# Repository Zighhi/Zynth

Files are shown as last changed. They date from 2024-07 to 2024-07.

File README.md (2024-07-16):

# Zynth

This was my Bachelor's degree project, where I designed a monophonic and semi-modular Digitally Controlled Analog Sound Synthesizer named **The Zynth**.

## Key Components

The synthesizer includes the following key components:

- **Voltage-Controlled Oscillators (VCOs):** Generates sine, triangle, sawtooth, and square waveforms.
- **Voltage-Controlled Filter (VCF):** Low-pass filter with adjustable cutoff frequency and resonance.
- **Voltage-Controlled Amplifier (VCA):** Modulates the amplitude of the synthesized signal.
- **Mixer:** Combines signals from the oscillator.
- **Amplitude Modulators:** Configurable ADSR envelope generator and LFO for modulation.
- **MIDI Interface:** Allows real-time musical note control.
- **Display:** Visualizes set parameters.

## Digital Control

The digital control is implemented using a Raspberry Pi Pico microcontroller, which manages the MIDI interface, ADSR envelope generator, LFO, other control signals, and the user interface.

## Features

- Real-time control via MIDI.
- Configurable waveform generation.
- Dynamic amplitude modulation.
- Adjustable filter parameters.

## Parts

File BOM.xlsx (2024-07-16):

Comment | Description | Designator | Footprint | LibRef | Quantity
2k | Axial Resistor, 100 Ohm, +/- 1%, 0.25 W, -55 to 155 degC, 2-Pin THD, RoHS, Bulk | 223, R205, R207, R209, R211, R215, R220, R221, R228, R231, R234 | RESA60-630X240 | CMP-009-00046-4 | 11
0.001u | Capacitor | C1, C2, C3 | S472M47Z5UP65K0R | S472M47Z5UP65K0R | 3
100p | Capacitor | C4, C20, C24, C25, C28, C34 | S101K29SL0N6TK5R | S101K29SL0N6TK5R | 6
0.1u | Vishay K104K15X7RF5TH5 100nF Multilayer Ceramic Capacitor MLCC 50V dc +/-10% Tolerance Through Hole | C5, C6, C7, C8, C12, C13, C14, C15, C17, C18, C19, C21, C22, C23, C26, C27, C29, C30, C31, C32, C33, C35, C36, C37, C38, C39, C40, C41, C44, C104, C106, C200, C202, C204, C206, C208, C210, C218, C220, C222, C224, C226, C227, C228, C229, C230, C231, C232, C234, C235, C236, C238, C239, C240, C242, C243, C244, C245, C246, C247, C249 | K104K15X7RF5TH5 | CMP-001-00088-1 | 61
22p | Capacitor | C9 | K220K15C0GH53L2 | K220K15C0GH53L2 | 1
4.7n | Capacitor | C10 | S472M47Z5UP65K0R | S472M47Z5UP65K0R | 1
220p | Capacitor | C11 | S472M47Z5UP65K0R | S472M47Z5UP65K0R | 1
47p | Capacitor | C16 | CC45SL3AD470JYVNA | CC45SL3AD470JYVNA | 1
10u | Vishay K104K15X7RF5TH5 100nF Multilayer Ceramic Capacitor MLCC 50V dc +/-10% Tolerance Through Hole | C42 | K104K15X7RF5TH5 | CMP-001-00088-1 | 1
30p | Capacitor | C43 | S300K25SL0N63L6R | S300K25SL0N63L6R | 1
3300u | Capacitor Polarised | C100, C101, C102, C107, C108, C109 | CAPPRD500W65D1250H3200 | CMP-001-00083-1 | 6
0.22u | Tantalum Capacitors - Solid Leaded 35V 0.22uF 10% ESR=17 Ohm | C103, C105 | TAP224K035SRW | CMP-001-00087-1 | 2
2.2u Tant | Tantalum Capacitors - Solid Leaded 35V 0.22uF 10% ESR=17 Ohm | C110, C112 | TAP224K035SRW | CMP-001-00087-1 | 2
1u Tant | Tantalum Capacitors - Solid Leaded 35V 1uF 20% ESR=8 Ohm | C111, C113 | TAP105M035SRW | CMP-001-00086-1 | 2
47u | Capacitor | C201 | FG22 | FG22X5R1A476MNT06 | 1
1u | Vishay K104K15X7RF5TH5 100nF Multilayer Ceramic Capacitor MLCC 50V dc +/-10% Tolerance Through Hole | C203, C205, C207, C209, C211, C212, C214, C216, C219, C221, C223, C225, C250, C251, C252, C253, C254, C255 | K104K15X7RF5TH5 | CMP-001-00088-1 | 18
10u | Capacitor Polarised | C213, C215, C217, C233, C237, C241, C248 | TAP106M016DCS | TAP106M016DCS | 7
1.3″ 128X64_OLED_DISPLAY | Monochrome 1.3 128x64 OLED graphic display | D | 1.3" 128X64_OLED_DISPLAY-Footpr | CMP-00000-2 | 1
1N5817 | DIODE SCHOTTKY 20V 1A DO41 | D1, D2, D3, D4, D6, D7 | FP-DO-41-MFG | CMP-12187-000037-1 | 6
1N914B | DIODE GEN PURP 100V 200MA DO35 | D5, D8, D9, D10, D11 | FP-017AG-MFG | CMP-07163-000001-1 | 5
1N4001G | Diode | D100, D101, D102, D103, D200 | DIOAD1405W86L465D235 | CMP-004-00031-1 | 5
Encoder | Rotary Encoder Breakoutboard | E | New footprint 1 | CMP-002-00074-3 | 1
TL084ACN | Integrated Circuit | IC1, IC2, IC4, IC5, IC6, IC7, IC8, IC9 | DIP794W53P254L1930H508Q14N | TL084ACN | 8
TL072IP | Integrated Circuit | IC3, U200, U215 | DIP794W53P254L959H508Q8N | CMP-031-00009-1 | 3
LM7812CT | Integrated Circuit | IC100 | TO254P470X1028X1955-3P | CMP-031-00007-1 | 1
LM7805CT | Linear voltage regulator,LM7805CT 5V 1A | IC101 | TO254P470X1028X1955-3P | CMP-031-00006-1 | 1
LM7912CT | TEXAS INSTRUMENTS - LM7912CT - IC | IC102 | TO254P470X1028X1955-3P | CMP-031-00008-1 | 1
LM7905CT | Integrated Circuit | IC103 | TO254P470X1028X1955-3P | CMP-031-00012-1 | 1
140-502-415-001 | Connector | J1, J2, J3, J4, J5, J201, J202 | 140502415001 | 140-502-415-001 | 7
SJ1-3525N | Connector | J6 | SJ13525N | SJ1-3525N | 1
PJ-002A | Through Hole Right Angle DC Power Jack, 2.5 A, 2 mm Center Pin, 3 Position, -25 to 85 degC, RoHS, Bulk | J100 | CUI-PJ-002A_V | CMP-2000-06895-2 | 1
57PC5F | CONN RCPT FMALE DIN 5POS SOLDER | J200 | FP-57PC5F-MFG | CMP-47988-000001-1 | 1
LTL-1CHG | LED Uni-Color Green, 100 mW, 30 mA, -55 to 100 degC, 2-Pin THD, RoHS, Bulk | LED | LTST-LTL-1CHG-2 | CMP-007-00019-2 | 1
BCM847BS-7 | Transistor BJT NPN | Q1 | SOT65P210X110-6N | BCM847BS-7 | 1
J310 | JFET VHF / UHF Amplifier, N-Channel - Depletion, 3-Pin TO-92, Bulk Box | Q2 | ONSC-TO-92-3-29-11 | CMP-1062-00074-1 | 1
BC857BS,115 | Transistor BJT PNP | Q3, Q4 | SOT65P210X110-6N | BC857BS,115 | 2
PC817X1J000F | OPTOISOLATOR 5KV TRANS 4DIP | Q200 | FP-PC817X1J000F-MFG | CMP-65434-000003-1 | 1
3M | Axial Resistor, 100 Ohm, +/- 1%, 0.25 W, -55 to 155 degC, 2-Pin THD, RoHS, Bulk | R1 | RESA60-630X240 | CMP-009-00046-4 | 1
100k | Axial Resistor, 100 Ohm, +/- 1%, 0.25 W, -55 to 155 degC, 2-Pin THD, RoHS, Bulk | R2, R3, R4, R5, R6, R7, R8, R10, R11, R12, R13, R14, R17, R18, R19, R20, R21, R23, R26, R28, R29, R38, R45, R53, R58, R59, R60, R61, R62, R63, R64, R65, R66, R67, R69, R70, R72, R75, R76, R79, R80, R81, R82, R83, R88, R91, R95, R96, R97, R101, R103, R106, R110, R116, R119, R120, R121, R202, R203 | RESA60-630X240 | CMP-009-00046-4 | 59
1M | Axial Resistor, 100 Ohm, +/- 1%, 0.25 W, -55 to 155 degC, 2-Pin THD, RoHS, Bulk | R9, R22, R36, R90, R107, R218, R226, R229, R236 | RESA60-630X240 | CMP-009-00046-4 | 9
200k | Axial Resistor, 100 Ohm, +/- 1%, 0.25 W, -55 to 155 degC, 2-Pin THD, RoHS, Bulk | R15, R54, R99, R109 | RESA60-630X240 | CMP-009-00046-4 | 4
4.7k | Axial Resistor, 100 Ohm, +/- 1%, 0.25 W, -55 to 155 degC, 2-Pin THD, RoHS, Bulk | R16 | RESA60-630X240 | CMP-009-00046-4 | 1
PTC | Axial Resistor, 100 Ohm, +/- 1%, 0.25 W, -55 to 155 degC, 2-Pin THD, RoHS, Bulk | R24 | RESA60-630X240 | CMP-009-00046-4 | 1
10k | Axial Resistor, 100 Ohm, +/- 1%, 0.25 W, -55 to 155 degC, 2-Pin THD, RoHS, Bulk | R25, R30, R31, R32, R33, R42, R44, R47, R48, R49, R50, R55, R77, R85, R108, R111, R122, R123 | RESA60-630X240 | CMP-009-00046-4 | 18
390 | Axial Resistor, 100 Ohm, +/- 1%, 0.25 W, -55 to 155 degC, 2-Pin THD, RoHS, Bulk | R27 | RESA60-630X240 | CMP-009-00046-4 | 1
12k | Axial Resistor, 100 Ohm, +/- 1%, 0.25 W, -55 to 155 degC, 2-Pin THD, RoHS, Bulk | R34, R46 | RESA60-630X240 | CMP-009-00046-4 | 2
20k | Axial Resistor, 100 Ohm, +/- 1%, 0.25 W, -55 to 155 degC, 2-Pin THD, RoHS, Bulk | R35 | RESA60-630X240 | CMP-009-00046-4 | 1
1k | Axial Resistor, 100 Ohm, +/- 1%, 0.25 W, -55 to 155 degC, 2-Pin THD, RoHS, Bulk | R37, R39, R56, R104, R204, R206, R208, R210, R212, R213, R214, R216, R217, R219, R222, R224, R225, R227, R230, R232, R233, R235 | RESA60-630X240 | CMP-009-00046-4 | 22
100 | Axial Resistor, 100 Ohm, +/- 1%, 0.25 W, -55 to 155 degC, 2-Pin THD, RoHS, Bulk | R40, R68, R73, R74, R84 | RESA60-630X240 | CMP-009-00046-4 | 6
150k | Axial Resistor, 100 Ohm, +/- 1%, 0.25 W, -55 to 155 degC, 2-Pin THD, RoHS, Bulk | R41, R43, R51 | RESA60-630X240 | CMP-009-00046-4 | 3
47k | Axial Resistor, 100 Ohm, +/- 1%, 0.25 W, -55 to 155 degC, 2-Pin THD, RoHS, Bulk | R57 | RESA60-630X240 | CMP-009-00046-4 | 1
30k | Axial Resistor, 100 Ohm, +/- 1%, 0.25 W, -55 to 155 degC, 2-Pin THD, RoHS, Bulk | R71, R89, R93, R102, R105 | RESA60-630X240 | CMP-009-00046-4 | 5
147k | Axial Resistor, 100 Ohm, +/- 1%, 0.25 W, -55 to 155 degC, 2-Pin THD, RoHS, Bulk | R78 | RESA60-630X240 | CMP-009-00046-4 | 1
120k | Axial Resistor, 100 Ohm, +/- 1%, 0.25 W, -55 to 155 degC, 2-Pin THD, RoHS, Bulk | R86, R98 | RESA60-630X240 | CMP-009-00046-4 | 2
21k | Axial Resistor, 100 Ohm, +/- 1%, 0.25 W, -55 to 155 degC, 2-Pin THD, RoHS, Bulk | R87 | RESA60-630X240 | CMP-009-00046-4 | 1
1.8k | Axial Resistor, 100 Ohm, +/- 1%, 0.25 W, -55 to 155 degC, 2-Pin THD, RoHS, Bulk | R92, R117 | RESA60-630X240 | CMP-009-00046-4 | 2
400k | Axial Resistor, 100 Ohm, +/- 1%, 0.25 W, -55 to 155 degC, 2-Pin THD, RoHS, Bulk | R94 | RESA60-630X240 | CMP-009-00046-4 | 1
500 | Axial Resistor, 100 Ohm, +/- 1%, 0.25 W, -55 to 155 degC, 2-Pin THD, RoHS, Bulk | R100, R201 | RESA60-630X240 | CMP-009-00046-4 | 2
475 | Axial Resistor, 100 Ohm, +/- 1%, 0.25 W, -55 to 155 degC, 2-Pin THD, RoHS, Bulk | R112 | RESA60-630X240 | CMP-009-00046-4 | 1
2.2k | Axial Resistor, 100 Ohm, +/- 1%, 0.25 W, -55 to 155 degC, 2-Pin THD, RoHS, Bulk | R113, R125 | RESA60-630X240 | CMP-009-00046-4 | 2
68k | Axial Resistor, 100 Ohm, +/- 1%, 0.25 W, -55 to 155 degC, 2-Pin THD, RoHS, Bulk | R114 | RESA60-630X240 | CMP-009-00046-4 | 1
1.2k | Axial Resistor, 100 Ohm, +/- 1%, 0.25 W, -55 to 155 degC, 2-Pin THD, RoHS, Bulk | R115 | RESA60-630X240 | CMP-009-00046-4 | 1
36k | Axial Resistor, 100 Ohm, +/- 1%, 0.25 W, -55 to 155 degC, 2-Pin THD, RoHS, Bulk | R118 | RESA60-630X240 | CMP-009-00046-4 | 1
2M | Axial Resistor, 100 Ohm, +/- 1%, 0.25 W, -55 to 155 degC, 2-Pin THD, RoHS, Bulk | R124 | RESA60-630X240 | CMP-009-00046-4 | 1
220 | Axial Resistor, 100 Ohm, +/- 1%, 0.25 W, -55 to 155 degC, 2-Pin THD, RoHS, Bulk | R200 | RESA60-630X240 | CMP-009-00046-4 | 1
RPI_PICO |  | RPI_PICO_W200 | RPI PICO 2020 | CMP-016-000000-3 | 1
PTH-M2D5X5 | M2 PTH (2.5mm), 5mm pad | ST1, ST2, ST3, ST4 | PTH-M2D5X5 | CMP-00028-00004-2 | 4
A101SYCB04 | SWITCH TOGGLE SPDT 0.4VA 20V | SW1 | FP-A101SYCB04-MFG | CMP-03408-000017-1 | 1
1825910-6 | Tact Switch, SPST-NO, 0.05 A, -35 to 85 degC, 4-Pin THD, RoHS, Bulk | SW200, SW201, SW202, SW203, SW204 | TECO-1825910-6_V | CMP-1684-00021-1 | 5
LM13700N | Dual Operational Transconductance Amplifier with Linearizing Diodes and Buffers, 16-pin MDIP | U1, U2, U3, U4 | NFG0016A | CMP-0055-00179-3 | 4
SN74HC138N | 3-Line To 8-Line Decoders/Demultiplexers, N0016A, TUBE | U201, U202 | N0016A | CMP-1633-00627-2 | 2
CD4049UBE | Integrated Circuit | U203, U204, U205 | DIP794W53P254L1930H508Q16N | CD4049UBE | 3
MCP4822-E_P | Integrated Circuit | U206, U208, U209 | DIP794W56P254L946H432Q8N | MCP4822-E_P | 3
CD4066BE | Integrated Circuit | U210, U211, U212, U213 | DIP794W53P254L1930H508Q14N | CD4066BE | 4
LM324N_NOPB | Integrated Circuit | U214, U216, U217, U218 | DIP794W56P254L1905H533Q14N | LM324N_NOPB | 4
100k | Potentiometers 200K LINEAR 20% | VR1, VR6, VR8, VR9, VR10, VR11, VR12, VR13 | PTV09A4020FB103 | CMP-011-000006-3 | 8
200k | Potentiometers 200K LINEAR 20% | VR2 | PTV09A4020FB103 | CMP-011-000006-3 | 1
3362P-1-103LF | Square Trimpot(R) Trimming Potentiometer, 10 KOhm, 300 V, -55 to 125 degC, 3-Pin THD, RoHS, Tube | VR3, VR4, VR5, VR7, VR14 | BOUR-3362P | CMP-009-00039-2 | 5
1k | Potentiometers 200K LINEAR 20% | VR15 | PTV09A4020FB103 | CMP-011-000006-3 | 1
15k | 'Axial Resistor, 100 Ohm, +/- 1%, 0.25 W, -55 to 155 degC, 2-Pin THD, RoHS, Bulk | R52 | RESA60-630X240 | CMP-009-00046-4 | 1

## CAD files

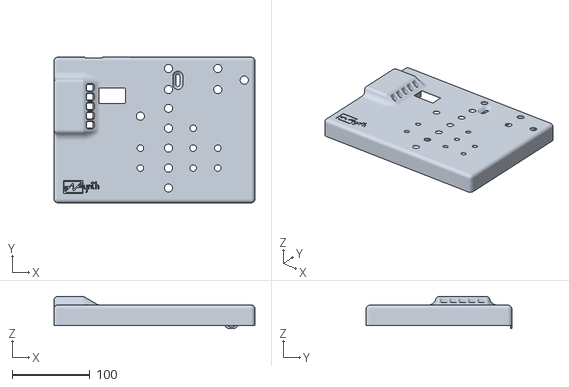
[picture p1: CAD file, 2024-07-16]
Case/Frontplate variants/Frontplate (w just logo).STL
258.0 x 187.0 x 41.1

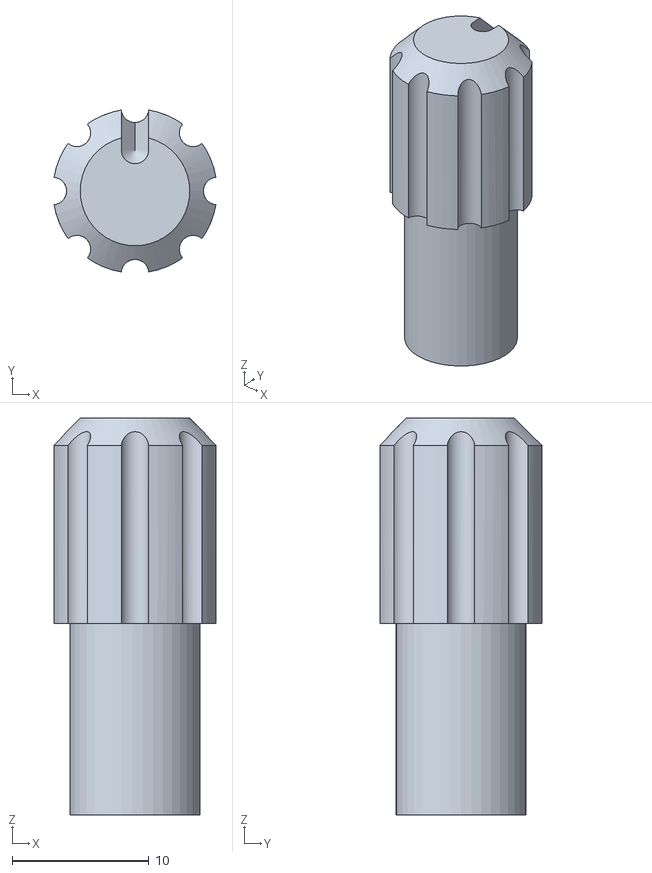
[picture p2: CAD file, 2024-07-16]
Case/Knob x10buc.STL
11.8 x 11.8 x 29.0

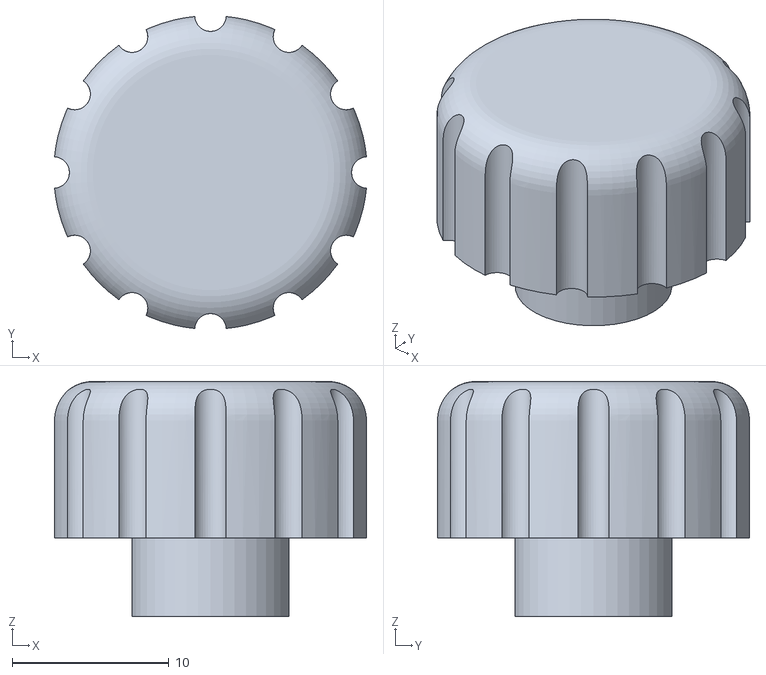
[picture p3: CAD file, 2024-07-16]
Case/EncoderKnob.STL
19.9 x 19.9 x 15.0

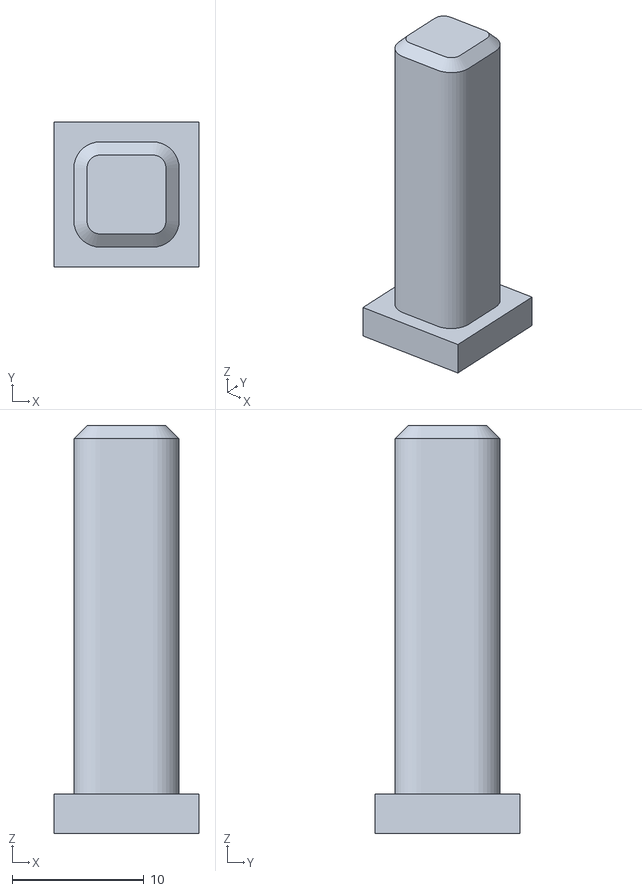
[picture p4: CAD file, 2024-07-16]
Case/Button x5buc.STL
11.0 x 11.0 x 31.0

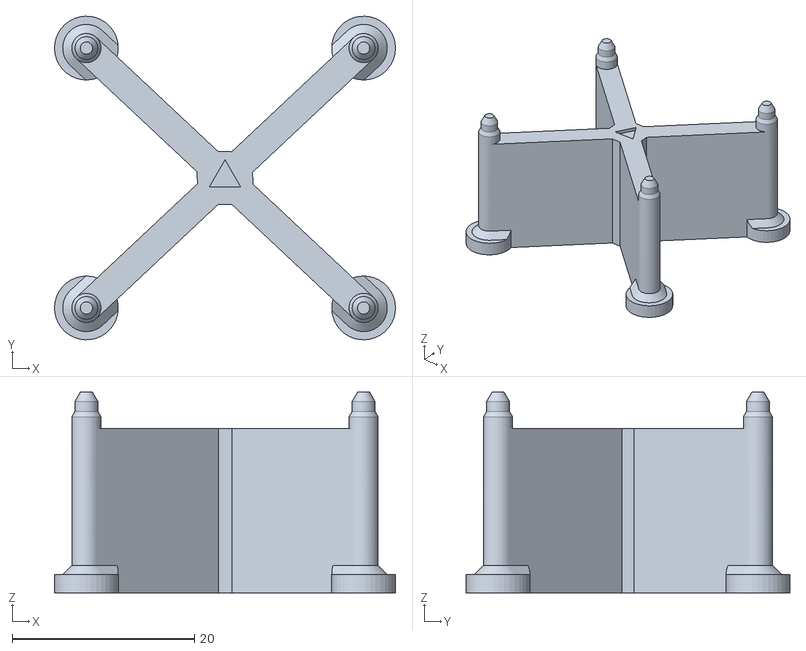
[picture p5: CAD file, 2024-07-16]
Case/DisplaySupport.STL
37.4 x 35.5 x 22.0

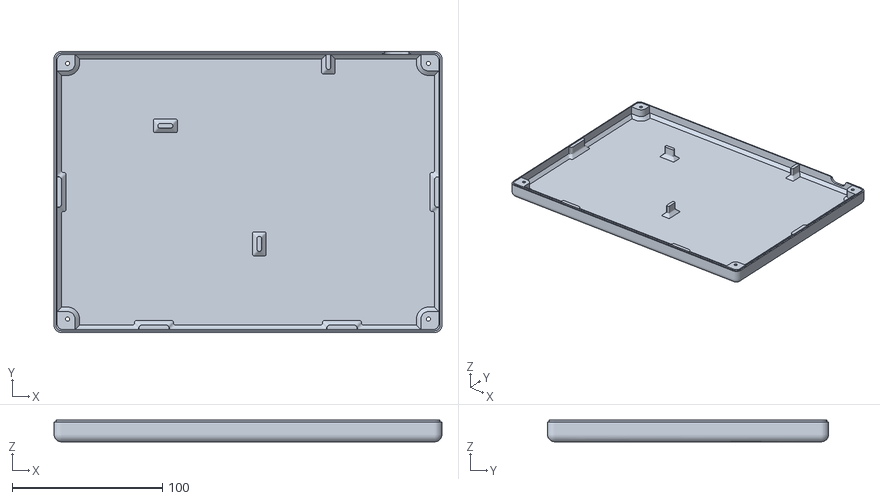
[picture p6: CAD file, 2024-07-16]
Case/Backplate.STL
258.0 x 187.0 x 14.4

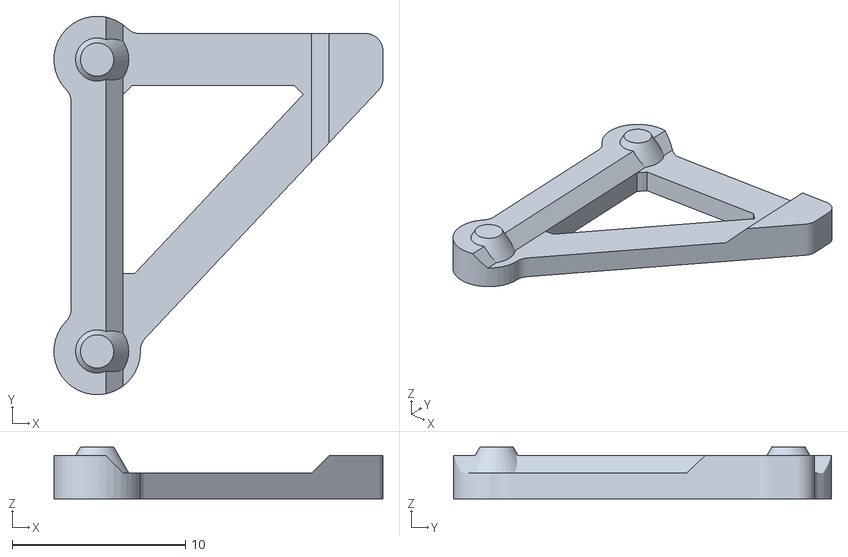
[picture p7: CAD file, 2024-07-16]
Case/EncoderSupport.STL
19.0 x 21.8 x 3.00

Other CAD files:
Case/Frontplate variants/Frontplate (blank).STL
Case/Frontplate.STL

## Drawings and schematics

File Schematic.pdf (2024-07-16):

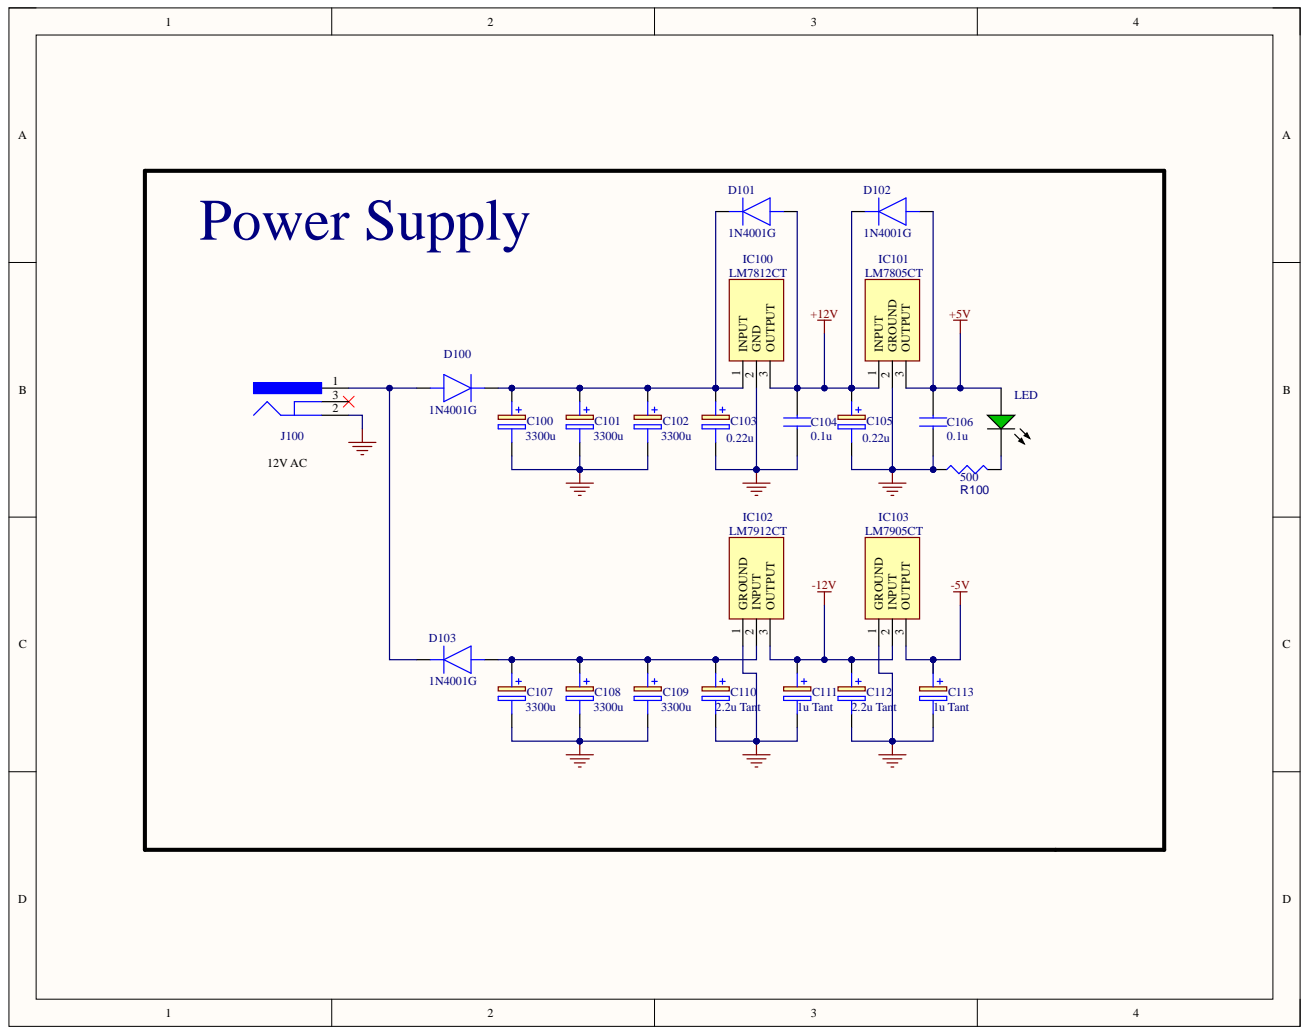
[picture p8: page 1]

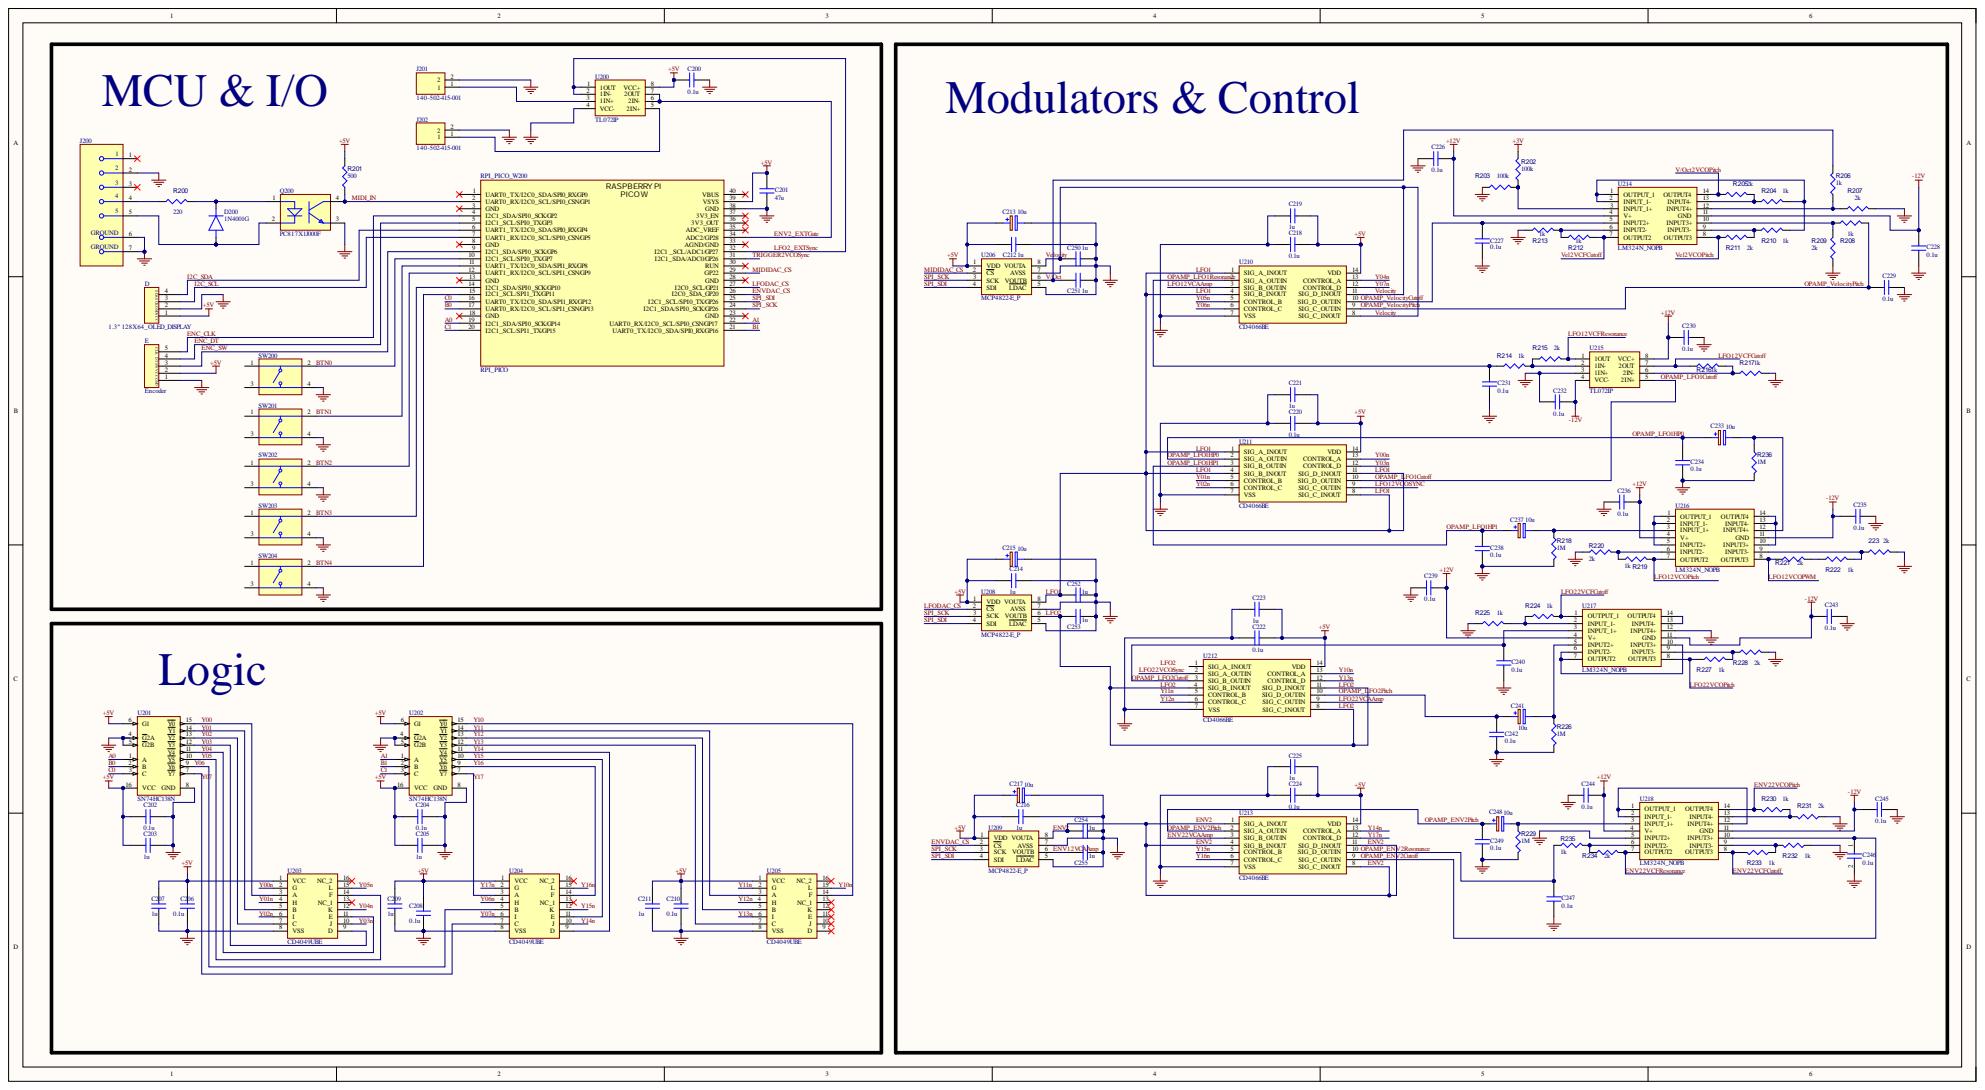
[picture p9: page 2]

1OUT 1 1IN- 2 2OUT 2IN+ | 7

VCC- 4 | 5 | +5V

ENC_SW

OPAMP_LFO1HP1 LFO1 | | SIG_B_OUT/IN 3 SIG_B_IN/OUT 4 | CONTROL_D | 12 Y03n LFO1

Y01n | | CONTROL_B 5 | | OPAMP_LFO1Cutoff

VSS 7 | | LFO1 | U216

LFO2 LFO22VCOSync | U212 | 0.1u | INPUT2- 6 INPUT3-OUTPUT3 | 9

OUTPUT2 7 | 8

Y11n | CONTROL_B 5 | OPAMP_LFO2Pitch

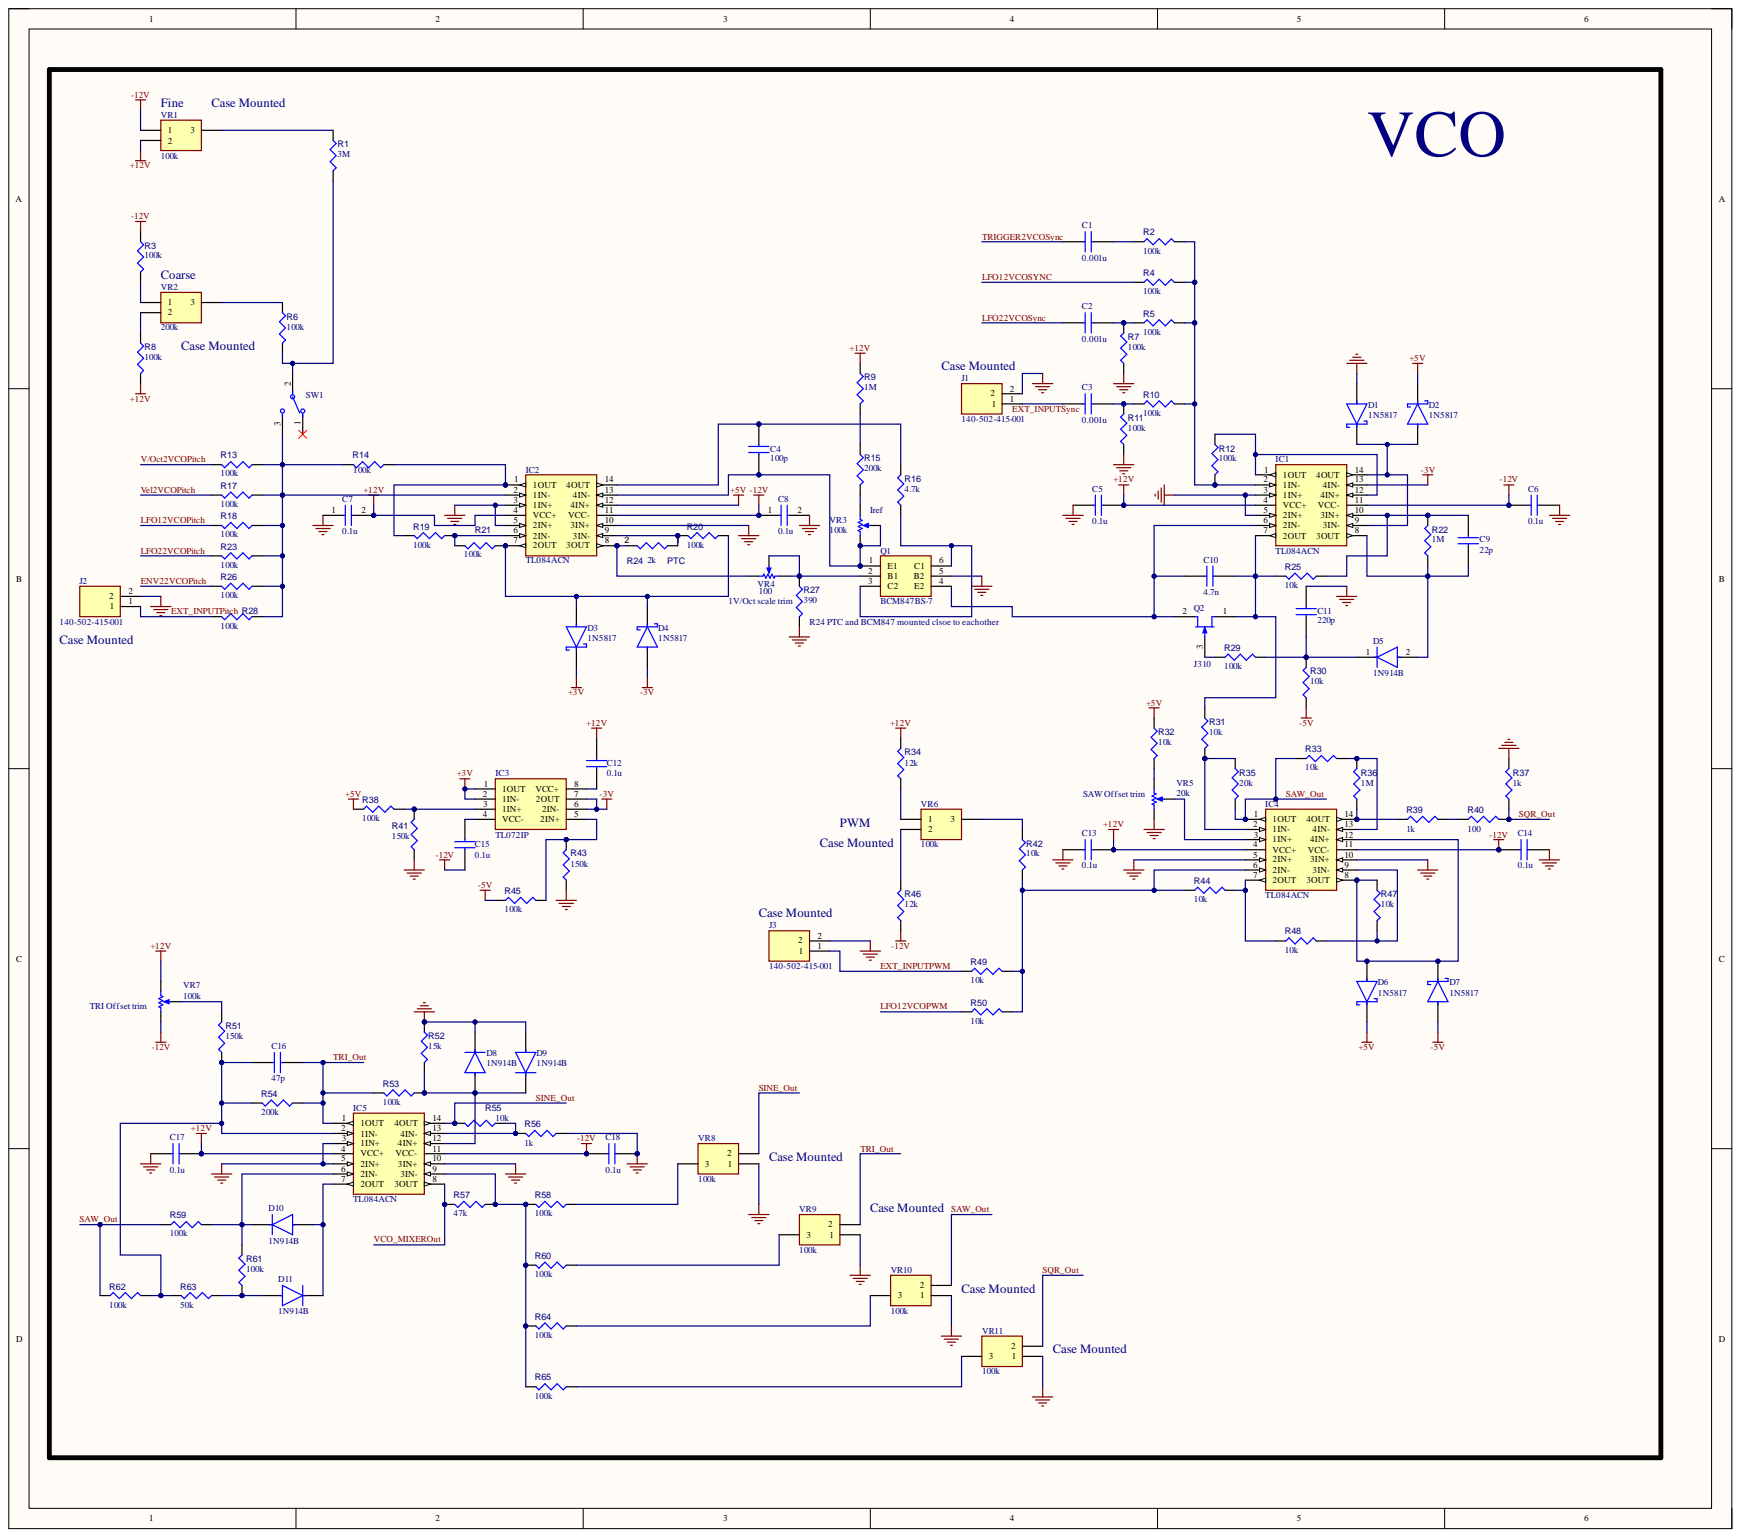
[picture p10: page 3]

2OUT 7 | 2 | 1

R24 2k PTC

R24 PTC and BCM847 mounted clsoe to eachother

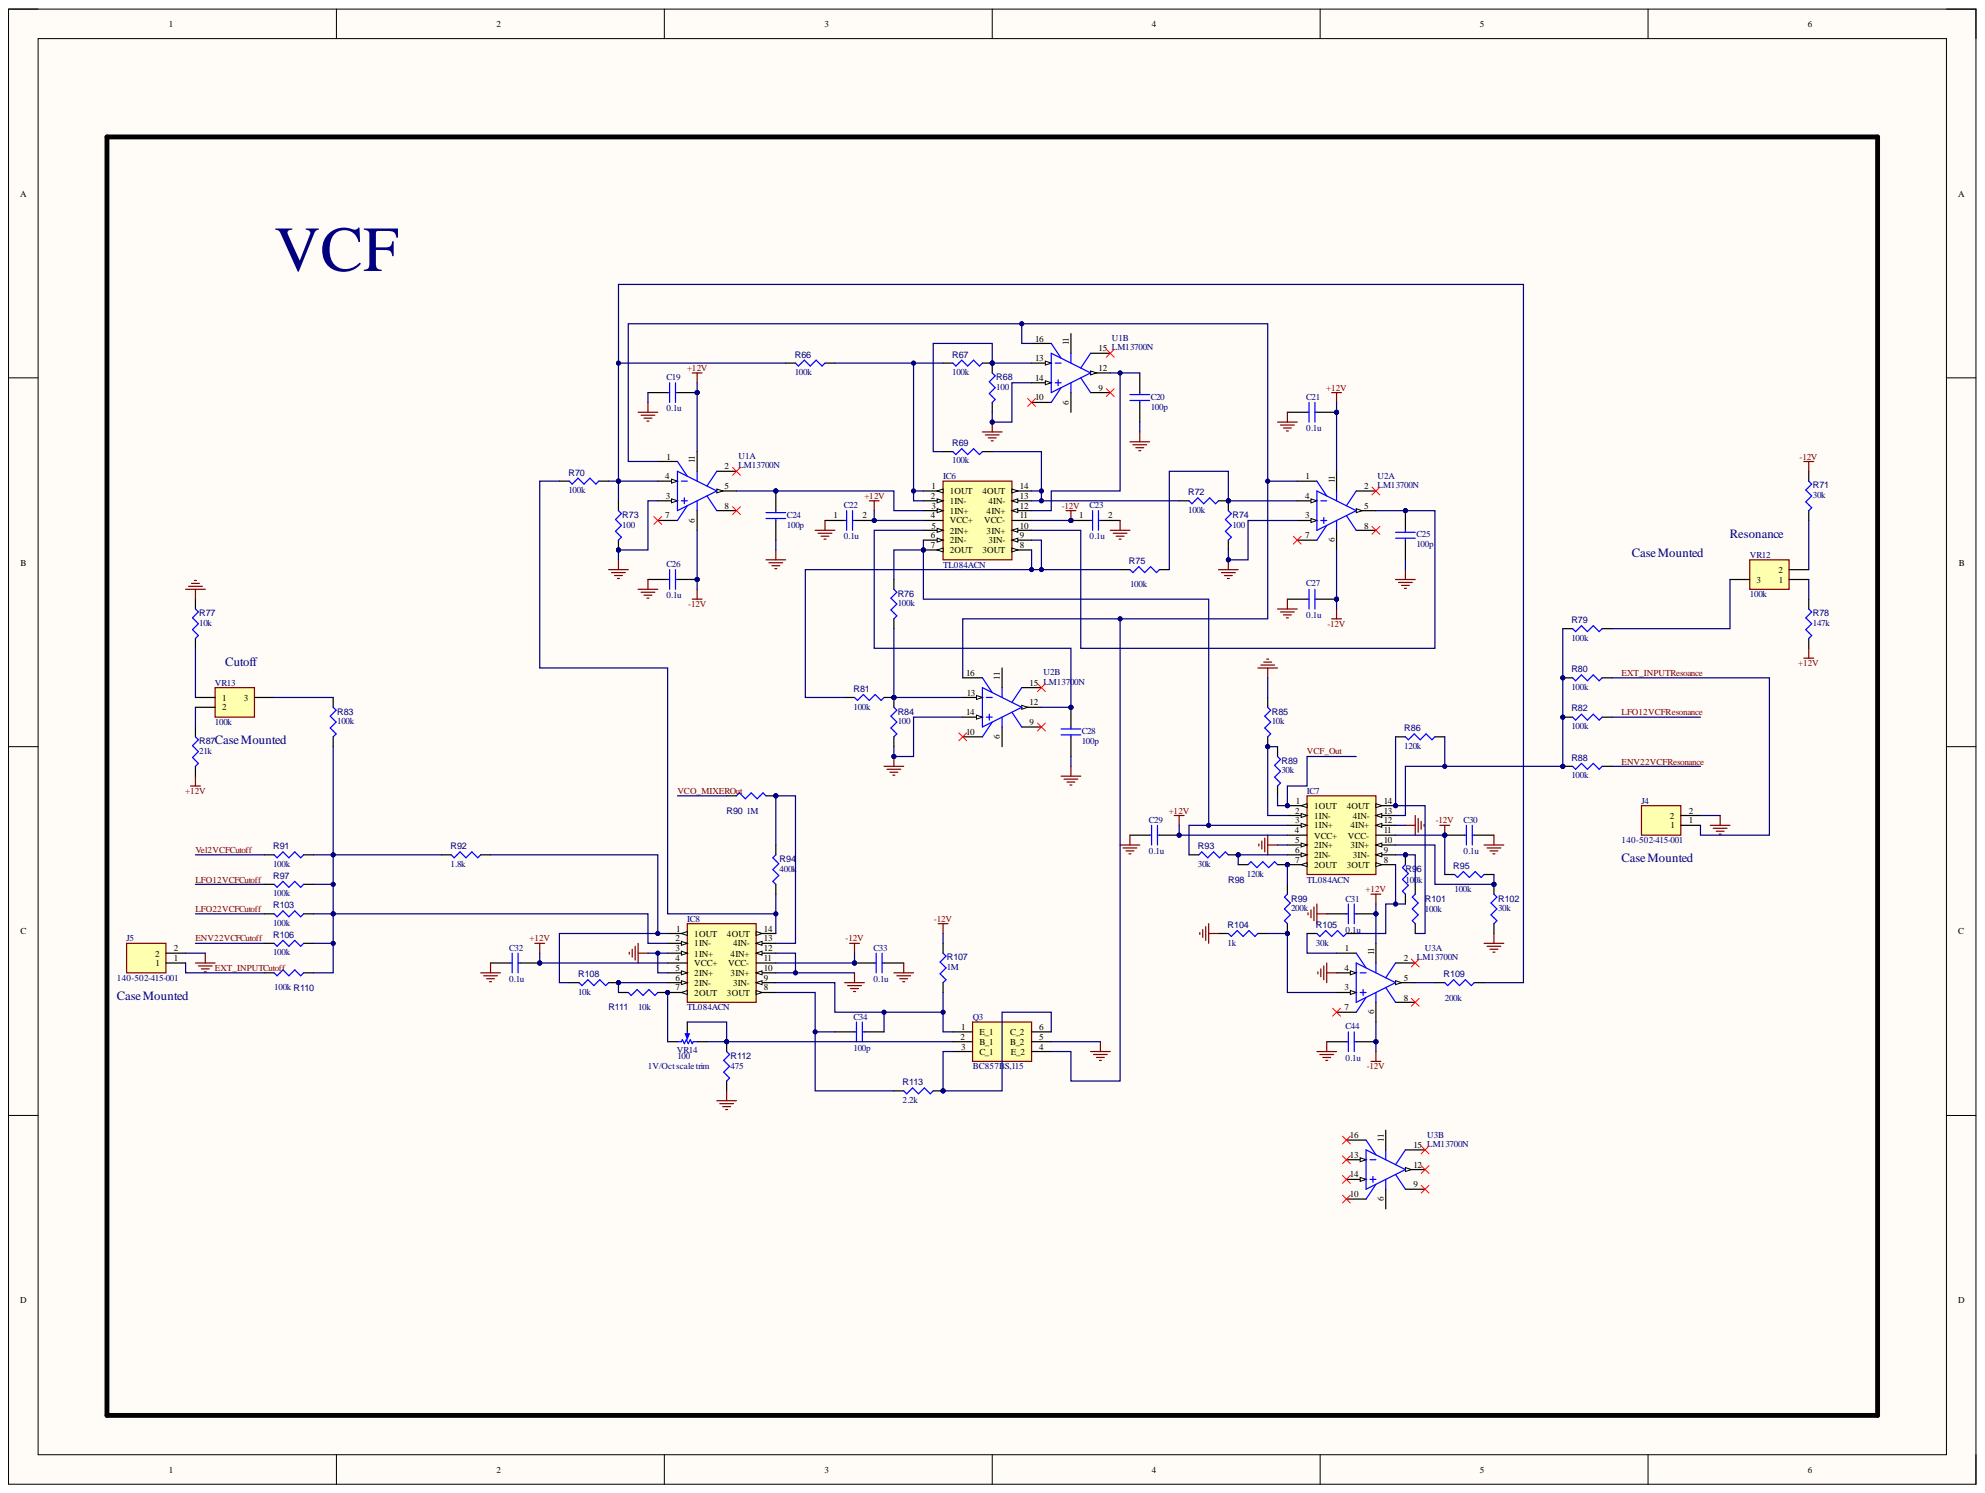
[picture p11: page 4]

2IN+ 5 | | | 100
2IN- 6 | 3OUT
2OUT 7 | 8

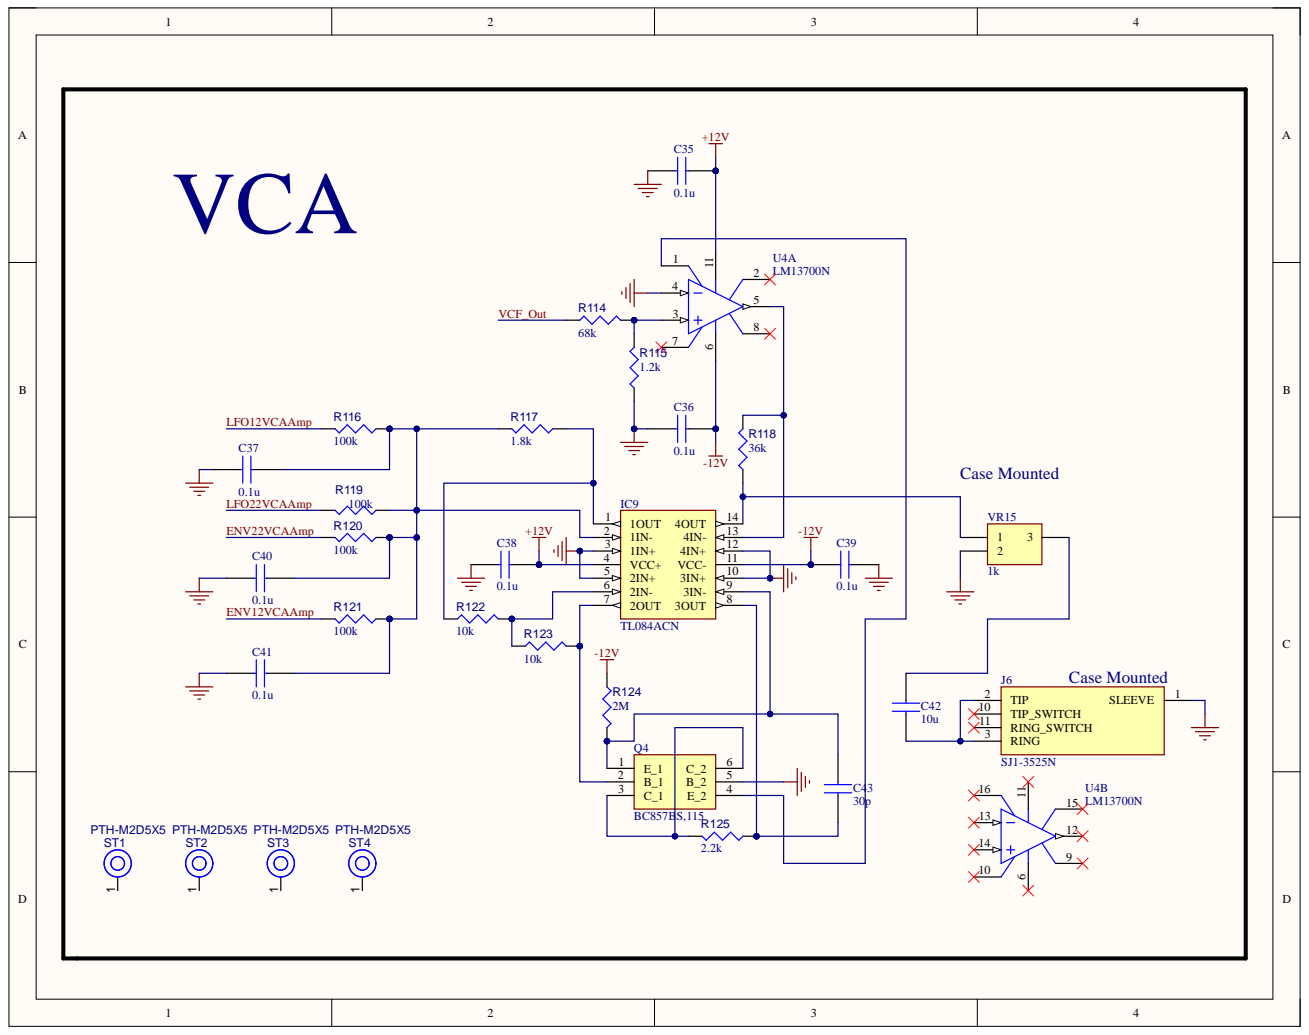
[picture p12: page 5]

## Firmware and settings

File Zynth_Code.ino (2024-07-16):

#include <MIDI.h>
#include <SoftwareSerial.h>
#include <SPI.h>
#include <Wire.h>
#include <adsr.h>
#include <lfo.h>
#include <U8g2lib.h>

//global Defines
#define SCREEN_WIDTH 128  // OLED display width, in pixels
#define SCREEN_HEIGHT 64  // OLED display height, in pixels
#define DACSIZE 4096      // Vertical resolution of the DACs

//Midi Serial
using Transport = MIDI_NAMESPACE::SerialMIDI<SoftwareSerial>;
int rxPin = 1;
int txPin = 0;
SoftwareSerial mySerial = SoftwareSerial(rxPin, txPin);
Transport serialMIDI(mySerial);
MIDI_NAMESPACE::MidiInterface<Transport> MIDI((Transport &)serialMIDI);

//MCP4822 registers
typedef unsigned int mcp4xxx_register;
const mcp4xxx_register mcp4822_channel_a = 0x5000;
const mcp4xxx_register mcp4822_channel_b = 0XD000;

//pins
const byte ENV_dac_cs = 20;    //ENV
const byte LFO_dac_cs = 21;    //LFO
const byte midi_dac1_cs = 22;  //NoteNumber
const byte TRIG = 26;
const byte ENV2_gate = 28;
const byte LFO2_sync = 27;
const byte ENC_A = 2;
const byte ENC_B = 3;
const byte ENC_btn = 6;

//Demultiplexor adress pins
const byte A_0 = 14;
const byte B_0 = 13;
const byte C_0 = 12;
const byte A_1 = 17;
const byte B_1 = 16;
const byte C_1 = 15;

//buttons
const byte btn0 = 7;
const byte btn1 = 8;
const byte btn2 = 9;
const byte btn3 = 10;
const byte btn4 = 11;

//Encoder Variables
unsigned long _lastIncReadTime = micros();
unsigned long _lastDecReadTime = micros();
int _pauseLength = 25000;
int _fastIncrement = 1000;

//Menu variables
int submenuSelection = 0;     // Variable to store the current submenu selection
unsigned long startTime = 0;  // Initialize variable
bool displayMenu = false;     // Flag to indicate when to display the menu
bool enterLFOMenu = false;    // Flag to indicate when to enter the LFO menu
bool enterENVMenu = false;    // Flag to indicate when to enter the ENV menu
bool enterMODMenu = false;    // Flag to indicate when to enter the MOD menu
int lastDisplayedMenu = 0;    // Variable to store the last displayed menu option
int LFOindex = 1;
int ENVindex = 1;

//MIDI variables
unsigned long startTime_midi = 0;  // Initialize variables
unsigned long elapsedTime = 0;
bool start = false;
int midiClockCount = 0;  // Initialize MIDI clock counter
float bpm = 120;
bool gateOpen = false;
bool noteOnReceived = false;
uint16_t velocity = 0;  //
float velocityPercent = 1;
uint16_t noteNumber = 0;

// adsr variables
unsigned long env1_attack = 100000;   // time in µs
unsigned long env1_decay = 100000;    // time in µs
int env1_sustain = DACSIZE / 2;       // sustain level -> from 0 to 4096-1
unsigned long env1_release = 100000;  // time in µs
float env1_amp = 1;

unsigned long env2_attack = 100000;   // time in µs
unsigned long env2_decay = 100000;    // time in µs
int env2_sustain = DACSIZE / 2;       // sustain level -> from 0 to 4096-1
unsigned long env2_release = 100000;  // time in µs
float env2_amp = 1;


//lfo variables
String wvfrms[5] = { "Off", "Saw", "Triangle", "Sin", "Square" };  // 0 -> off, 1 -> saw, 2 -> triangle, 3 -> sin, 4 -> square [0,4]
bool lfo1Mode = false;                                             //free running
bool lfo2Mode = false;
float lfo_mode1_rate[19] = { 0.125, 0.25, 0.5, 1, 2, 3, 4, 5, 6, 7, 8, 9, 10, 11, 12, 13, 14, 15, 16 };
String lfo_mode1_rateStrings[19] = { "2", "1", "1/2", "1/4", "1/8", "1/12", "1/16", "1/20", "1/24", "1/28", "1/32", "1/36", "1/40", "1/44", "1/48", "1/52", "1/56", "1/60", "1/64" };
int lfo1_waveformIndex = 1;
int lfo2_waveformIndex = 1;
int lfo1_amp = DACSIZE - 1;
int lfo2_amp = DACSIZE - 1;
float lfo1_freq = 10;
float lfo2_freq = 10;
int lfo1_rateIndex = 0;
float lfo1_rate = lfo_mode1_rate[lfo1_rateIndex];
int lfo2_rateIndex = 0;
float lfo2_rate = lfo_mode1_rate[lfo2_rateIndex];

//MOD menu variables
String lfo1_paths[8] = { "None", "Pitch", "PWM", "SYNC", "Cutoff", "Resonance", "Amp", "ENV2 Trigger" };
int lfo1_pathsIndex = 0;
String lfo2_paths[6] = { "None", "Pitch", "SYNC", "Cutoff", "Amp", "ENV2 Trigger" };
int lfo2_pathsIndex = 0;
String env2_paths[5] = { "None", "Pitch", "Amp", "Cutoff", "Resonance" };
int env2_pathsIndex = 0;
String trigger_paths[5] = { "None", "SYNC", "LFO1 SYNC", "LFO2 SYNC", "ENV2 Trigger" };
int trigger_pathsIndex = 0;
String velocity_paths[3] = { "None", "Cutoff", "Pitch" };
int velocity_pathsIndex = 1;
bool trigger2SYNC = false;
bool trigger2LFO1 = false;
bool trigger2LFO2 = false;
bool trigger2ENV2 = false;
bool lfo12ENV2 = false;
bool lfo22ENV2 = false;
bool velocity2Pitch = false;
bool velocity2Cutoff = false;

adsr env1(DACSIZE);  // ADSR class initialization
adsr env2(DACSIZE);
lfo lfo1(DACSIZE);  // LFO class initialization
lfo lfo2(DACSIZE);
U8G2_SH1106_128X64_NONAME_F_HW_I2C u8g2(U8G2_R0, U8X8_PIN_NONE);

//Logo bitmap
static const uint8_t PROGMEM logo[] = {
  0x00, 0x00, 0x00, 0x00, 0x00, 0x00, 0x00, 0x00, 0x00, 0x00, 0x00, 0x00, 0x00, 0x00, 0x00, 0x00,
  0x00, 0x00, 0x00, 0x00, 0x00, 0x00, 0x00, 0x00, 0x00, 0x00, 0x00, 0x00, 0x00, 0x00, 0x00, 0x00,
  0x00, 0x00, 0x00, 0x00, 0x00, 0x00, 0x00, 0x00, 0x00, 0x00, 0x00, 0x00, 0x00, 0x00, 0x00, 0x00,
  0x00, 0x00, 0x00, 0x00, 0x00, 0x00, 0x00, 0x00, 0x00, 0x00, 0x00, 0x00, 0x00, 0x00, 0x00, 0x00,
  0x00, 0x00, 0x00, 0x00, 0x00, 0x00, 0x00, 0x00, 0x00, 0x00, 0x00, 0x00, 0x00, 0x00, 0x00, 0x00,
  0x00, 0x00, 0x00, 0x00, 0x00, 0x00, 0x00, 0x00, 0x00, 0x00, 0x00, 0x00, 0x00, 0x00, 0x00, 0x00,
  0x00, 0x00, 0x00, 0x00, 0x00, 0x00, 0x00, 0x00, 0x00, 0x00, 0x00, 0x00, 0x00, 0x00, 0x00, 0x00,
  0x00, 0x00, 0x00, 0x00, 0x00, 0x00, 0x00, 0x00, 0x00, 0x00, 0x00, 0x00, 0x00, 0x00, 0x00, 0x00,
  0x00, 0x00, 0x00, 0x00, 0x00, 0x00, 0x00, 0x00, 0x00, 0x00, 0x00, 0x00, 0x00, 0x00, 0x00, 0x00,
  0x00, 0x00, 0x00, 0x00, 0x00, 0x00, 0x00, 0x00, 0x00, 0x00, 0x00, 0x00, 0x00, 0x00, 0x00, 0x00,
  0x00, 0x00, 0x00, 0x00, 0x00, 0x00, 0x00, 0x00, 0x00, 0x00, 0x00, 0x00, 0x00, 0x00, 0x00, 0x00,
  0x00, 0x00, 0x00, 0x00, 0x00, 0x00, 0x00, 0x00, 0x00, 0x00, 0x00, 0x00, 0x00, 0x00, 0x00, 0x00,
  0x00, 0x00, 0x00, 0x00, 0x00, 0x00, 0x00, 0x00, 0x00, 0x00, 0x00, 0x00, 0x00, 0x00, 0x00, 0x00,
  0x00, 0xf8, 0xff, 0xff, 0xff, 0xff, 0xff, 0xff, 0x03, 0x00, 0x00, 0x00, 0x00, 0x00, 0x00, 0x00,
  0x00, 0xfc, 0xff, 0xff, 0xff, 0xff, 0xff, 0xff, 0x07, 0x00, 0x00, 0x00, 0x00, 0x38, 0x00, 0x00,
  0x00, 0xfc, 0xff, 0xff, 0xff, 0xff, 0xff, 0xff, 0x07, 0x00, 0x00, 0x00, 0x0e, 0x38, 0x00, 0x00,
  0x00, 0x0c, 0x00, 0x00, 0x00, 0x00, 0x00, 0xf8, 0x07, 0x00, 0x00, 0x00, 0x0e, 0x38, 0x00, 0x00,
  0x00, 0x0c, 0x00, 0x00, 0x00, 0x00, 0x00, 0xf0, 0x07, 0x00, 0x00, 0xe0, 0xff, 0x38, 0x00, 0x00,
  0x00, 0x0c, 0x00, 0x00, 0x00, 0x00, 0x00, 0xf0, 0x07, 0x00, 0x00, 0xe0, 0x7f, 0x38, 0x00, 0x00,
  0x00, 0x0c, 0x00, 0x00, 0x00, 0x00, 0x00, 0xf8, 0x07, 0x00, 0x00, 0xe0, 0xff, 0x38, 0x00, 0x00,
  0x00, 0x0c, 0x00, 0x00, 0x00, 0x00, 0x00, 0xfc, 0x07, 0x00, 0x00, 0x00, 0x0e, 0x38, 0x00, 0x00,
  0x00, 0x0c, 0x00, 0x00, 0x00, 0x00, 0x00, 0x0c, 0x07, 0x00, 0x00, 0x00, 0x0e, 0x38, 0x00, 0x00,
  0x00, 0x0c, 0x00, 0x00, 0x78, 0x00, 0x00, 0x06, 0x07, 0x00, 0x00, 0x00, 0x0e, 0x38, 0x00, 0x00,
  0x00, 0x0c, 0x00, 0x00, 0x78, 0x00, 0x00, 0x03, 0x07, 0x00, 0x00, 0x00, 0x0e, 0x38, 0x00, 0x00,
  0x00, 0x0c, 0x00, 0x00, 0x7c, 0x00, 0xc0, 0x11, 0x07, 0x00, 0x00, 0x00, 0x0e, 0x38, 0x00, 0x00,
  0x00, 0x0c, 0x00, 0x00, 0x7e, 0x00, 0xe0, 0x3c, 0x07, 0x00, 0xf8, 0x01, 0x0e, 0xf8, 0x0f, 0x00,
  0x00, 0x0c, 0x00, 0x00, 0x7f, 0x00, 0xe0, 0x7c, 0xe7, 0xc0, 0xf9, 0x77, 0x0e, 0xf8, 0x1f, 0x00,
  0x00, 0x0c, 0x00, 0x80, 0x73, 0x00, 0x70, 0x7c, 0xe7, 0xc0, 0xf9, 0x7f, 0x0e, 0xf8, 0x3e, 0x00,
  0x00, 0x0c, 0x00, 0xc0, 0x61, 0x00, 0x38, 0x38, 0xe7, 0xc0, 0x39, 0x7e, 0x0e, 0x78, 0x38, 0x00,
  0x00, 0x0c, 0x00, 0xe0, 0x60, 0x00, 0x7c, 0x00, 0xe7, 0xc0, 0x39, 0x7c, 0x0e, 0x38, 0x30, 0x00,
  0x00, 0x1c, 0x00, 0x70, 0x60, 0x00, 0x7e, 0x00, 0xe7, 0xc0, 0x39, 0x78, 0x0e, 0x38, 0x70, 0x00,
  0x00, 0xfc, 0xff, 0x3f, 0x60, 0x00, 0xff, 0xff, 0xe7, 0xc0, 0x39, 0x78, 0x0e, 0x38, 0x70, 0x00,
  0x00, 0xfc, 0xff, 0x1f, 0x60, 0x80, 0xff, 0xff, 0xe7, 0xc0, 0x39, 0x70, 0x0e, 0x38, 0x70, 0x00,
  0x00, 0x1c, 0xc0, 0x0f, 0x60, 0xc0, 0x01, 0x00, 0xe7, 0xc0, 0x39, 0x70, 0x0e, 0x38, 0x70, 0x00,
  0x00, 0x0c, 0xc0, 0x07, 0x60, 0xe0, 0x00, 0x00, 0xe7, 0xc0, 0x39, 0x70, 0x0e, 0x38, 0x70, 0x00,
  0x00, 0xcc, 0xc3, 0x03, 0xe0, 0x70, 0x00, 0x00, 0xc7, 0xe1, 0x39, 0x70, 0x0e, 0x38, 0x70, 0x00,
  0x00, 0xcc, 0xc3, 0x01, 0xe0, 0x38, 0x00, 0x00, 0xc7, 0xff, 0x39, 0x70, 0x3c, 0x38, 0x70, 0x00,
  0x00, 0xcc, 0xe7, 0x00, 0xe0, 0x1f, 0x00, 0x00, 0x87, 0xff, 0x39, 0x70, 0xf8, 0x38, 0x30, 0x00,
  0x00, 0xcc, 0x73, 0x00, 0xe0, 0x0f, 0x00, 0x00, 0x07, 0xff, 0x01, 0x50, 0xf0, 0x00, 0x00, 0x00,
  0x00, 0x0c, 0x39, 0x00, 0xe0, 0x07, 0x00, 0x00, 0x07, 0xc0, 0x01, 0x00, 0x00, 0x00, 0x00, 0x00,
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
};

void setup() {
  pinMode(ENV_dac_cs, OUTPUT);
  digitalWrite(ENV_dac_cs, HIGH);
  pinMode(LFO_dac_cs, OUTPUT);
  digitalWrite(LFO_dac_cs, HIGH);
  pinMode(midi_dac1_cs, OUTPUT);
  digitalWrite(midi_dac1_cs, HIGH);

  pinMode(A_0, OUTPUT);
  digitalWrite(A_0, LOW);
  pinMode(B_0, OUTPUT);
  digitalWrite(B_0, LOW);
  pinMode(C_0, OUTPUT);
  digitalWrite(C_0, LOW);
  pinMode(A_1, OUTPUT);
  digitalWrite(A_1, LOW);
  pinMode(B_1, OUTPUT);
  digitalWrite(B_1, LOW);
  pinMode(C_1, OUTPUT);
  digitalWrite(C_1, LOW);


  pinMode(TRIG, OUTPUT);
  digitalWrite(TRIG, HIGH);

  pinMode(btn0, INPUT_PULLUP);
  pinMode(btn1, INPUT_PULLUP);
  pinMode(btn2, INPUT_PULLUP);
  pinMode(btn3, INPUT_PULLUP);
  pinMode(btn4, INPUT_PULLUP);

  pinMode(ENV2_gate, INPUT_PULLDOWN);
  pinMode(LFO2_sync, INPUT_PULLDOWN);

  // Set encoder pins and attach interrupts
  pinMode(ENC_A, INPUT_PULLUP);
  pinMode(ENC_B, INPUT_PULLUP);
  pinMode(ENC_btn, INPUT_PULLUP);
  attachInterrupt(digitalPinToInterrupt(ENC_A), read_encoder, CHANGE);
  attachInterrupt(digitalPinToInterrupt(ENC_B), read_encoder, CHANGE);
  //attachInterrupt(digitalPinToInterrupt(ENC_btn), toggleControlMode, FALLING);

  Serial.begin(9600);  // Initialize serial communication for printing
  MIDI.begin(1);

  env1.setAttack(env1_attack);    // initialize attack
  env1.setDecay(env1_decay);      // initialize decay
  env1.setSustain(env1_sustain);  // initialize sustain
  env1.setRelease(env1_release);  // initialize release

  env2.setAttack(env2_attack);    // initialize attack
  env2.setDecay(env2_decay);      // initialize decay
  env2.setSustain(env2_sustain);  // initialize sustain
  env2.setRelease(env2_release);  // initialize release

  lfo1.setWaveForm(1);
  lfo1.setAmpl(DACSIZE - 1);
  lfo1.setAmplOffset(0);
  lfo1.setMode(0);
  lfo1.setMode0Freq(10);

  lfo2.setWaveForm(1);
  lfo2.setAmpl(DACSIZE - 1);
  lfo2.setAmplOffset(0);
  lfo1.setMode(0);
  lfo2.setMode0Freq(10);

  u8g2.begin();
  u8g2.clearBuffer();  // clear the internal memory

  u8g2.firstPage();
  do {
    u8g2.drawXBMP(0, 0, SCREEN_WIDTH, SCREEN_HEIGHT, logo);
  } while (u8g2.nextPage());

  u8g2.sendBuffer();     // transfer internal memory to the display
  startTime = millis();  // Record the start time

  SPI.begin();
}

void loop() {
  // Check if it's time to display the menu
  if (millis() - startTime >= 5000 && !displayMenu) {
    displayMenu = true;
    updateDisplay(submenuSelection);  // Display the menu
  }
  // Check for button press to toggle MIDI menu
  if (digitalRead(ENC_btn) == LOW) {
    if (submenuSelection == 1) {
      enterENVMenu = !enterENVMenu;  // Toggle ENV menu flag
      if (enterENVMenu) {
        // Reset the ENV index to 1 when entering the ENV menu
        ENVindex = 1;
      }
      if (!enterENVMenu) {
        // Store the last displayed menu option before exiting the menu
        lastDisplayedMenu = submenuSelection;
      }
      updateDisplay(enterENVMenu ? submenuSelection : lastDisplayedMenu);  // Update the display
      delay(200);                                                          // Add a small delay to debounce the button
    } else if (submenuSelection == 0) {
      enterLFOMenu = !enterLFOMenu;  // Toggle LFO menu flag
      if (enterLFOMenu) {
        // Reset the LFO index to 1 when entering the LFO menu
        LFOindex = 1;
      }
      if (!enterLFOMenu) {
        // Store the last displayed menu option before exiting the menu
        lastDisplayedMenu = submenuSelection;
      }
      updateDisplay(enterLFOMenu ? submenuSelection : lastDisplayedMenu);  // Update the display
      delay(200);                                                          // Add a small delay to debounce the button
    } else if (submenuSelection == 2) {
      enterMODMenu = !enterMODMenu;  // Toggle MOD menu flag
      if (!enterMODMenu) {
        // Store the last displayed menu option before exiting the menu
        lastDisplayedMenu = submenuSelection;
      }
      updateDisplay(enterMODMenu ? submenuSelection : lastDisplayedMenu);  // Update the display
      delay(200);                                                          // Add a small delay to debounce the button
    } else if (enterENVMenu) {
      // If in the ENV menu and the button is pressed again, exit the menu
      enterENVMenu = false;
      updateDisplay(lastDisplayedMenu);  // Update the display to show the last displayed menu option
      delay(200);                        // Add a small delay to debounce the button
    } else if (enterLFOMenu) {
      // If in the LFO menu and the button is pressed again, exit the menu
      enterLFOMenu = false;
      updateDisplay(lastDisplayedMenu);  // Update the display to show the last displayed menu option
      delay(200);                        // Add a small delay to debounce the button
    } else if (enterMODMenu) {
      // If in the MOD menu and the button is pressed again, exit the menu
      enterMODMenu = false;
      updateDisplay(lastDisplayedMenu);  // Update the display to show the last displayed menu option
      delay(200);                        // Add a small delay to debounce the button
    }
  }

  // Add this condition to exit the ENV menu when you press the button again
  if (enterENVMenu && digitalRead(ENC_btn) == LOW) {
    enterENVMenu = false;              // Exit the ENV menu
    updateDisplay(lastDisplayedMenu);  // Update the display to show the last displayed menu option
    delay(200);                        // Add a small delay to debounce the button
  }

  // Add this condition to exit the LFO menu when you press the button again
  if (enterLFOMenu && digitalRead(ENC_btn) == LOW) {
    enterLFOMenu = false;              // Exit the LFO menu
    updateDisplay(lastDisplayedMenu);  // Update the display to show the last displayed menu option
    delay(200);                        // Add a small delay to debounce the button
  }

  // Add this condition to exit the LFO menu when you press the button again
  if (enterMODMenu && digitalRead(ENC_btn) == LOW) {
    enterMODMenu = false;              // Exit the LFO menu
    updateDisplay(lastDisplayedMenu);  // Update the display to show the last displayed menu option
    delay(200);                        // Add a small delay to debounce the button
  }

  setVoltage(ENV_dac_cs, mcp4822_channel_b, env1.getWave(micros()) * env1_amp);

  switch (env2_pathsIndex) {  //"None", "Pitch", "Amp", "Cutoff", "Resonance"
    case 0:
      setVoltage(ENV_dac_cs, mcp4822_channel_a, 0);
      break;
    case 1:
      setVoltage(ENV_dac_cs, mcp4822_channel_a, env2.getWave(micros()) * env2_amp);
      digitalWrite(A_1, LOW);
      digitalWrite(B_1, LOW);
      digitalWrite(C_1, HIGH);
      break;
    case 2:
      setVoltage(ENV_dac_cs, mcp4822_channel_a, env2.getWave(micros()) * env2_amp);
      digitalWrite(A_1, HIGH);
      digitalWrite(B_1, LOW);
      digitalWrite(C_1, HIGH);
      break;
    case 3:
      setVoltage(ENV_dac_cs, mcp4822_channel_a, env2.getWave(micros()) * env2_amp);
      digitalWrite(A_1, LOW);
      digitalWrite(B_1, HIGH);
      digitalWrite(C_1, HIGH);
      break;
    case 4:
      setVoltage(ENV_dac_cs, mcp4822_channel_a, env2.getWave(micros()) * env2_amp);
      digitalWrite(A_1, HIGH);
      digitalWrite(B_1, HIGH);
      digitalWrite(C_1, HIGH);
      break;
    default:
      break;
  }


  lfo1.setWaveForm(lfo1_waveformIndex);
  lfo1.setAmpl(lfo1_amp);
  if (!lfo1Mode) {
    lfo1.setMode(lfo1Mode);
    lfo1.setMode0Freq(lfo1_freq, micros());
  } else {
    lfo1.setMode(lfo1Mode);
    lfo1.setMode1Bpm(bpm);
    lfo1.setMode1Rate(lfo1_rate);
  }

  switch (lfo1_pathsIndex) {  //"None", "Pitch", "PWM", "SYNC", "Cutoff", "Resonance", "Amp", "ENV2 EXT Trigger"
    case 0:
      lfo12ENV2 = false;
      setVoltage(LFO_dac_cs, mcp4822_channel_a, 0);
      break;
    case 1:
      lfo12ENV2 = false;
      setVoltage(LFO_dac_cs, mcp4822_channel_a, lfo1.getWave(micros()));
      digitalWrite(A_0, HIGH);
      digitalWrite(B_0, LOW);
      digitalWrite(C_0, LOW);
      break;
    case 2:
      lfo12ENV2 = false;
      setVoltage(LFO_dac_cs, mcp4822_channel_a, lfo1.getWave(micros()));
      digitalWrite(A_0, LOW);
      digitalWrite(B_0, LOW);
      digitalWrite(C_0, LOW);
      break;
    case 3:
      lfo12ENV2 = false;
      setVoltage(LFO_dac_cs, mcp4822_channel_a, lfo1.getWave(micros()));
      digitalWrite(A_0, LOW);
      digitalWrite(B_0, HIGH);
      digitalWrite(C_0, LOW);
      break;
    case 4:
      lfo12ENV2 = false;
      setVoltage(LFO_dac_cs, mcp4822_channel_a, lfo1.getWave(micros()));
      digitalWrite(A_0, HIGH);
      digitalWrite(B_0, HIGH);
      digitalWrite(C_0, LOW);
      break;
    case 5:
      lfo12ENV2 = false;
      setVoltage(LFO_dac_cs, mcp4822_channel_a, lfo1.getWave(micros()));
      digitalWrite(A_0, LOW);
      digitalWrite(B_0, LOW);
      digitalWrite(C_0, HIGH);
      break;
    case 6:
      lfo12ENV2 = false;
      setVoltage(LFO_dac_cs, mcp4822_channel_a, lfo1.getWave(micros()));
      digitalWrite(A_0, HIGH);
      digitalWrite(B_0, LOW);
      digitalWrite(C_0, HIGH);
      break;
    case 7:
      lfo12ENV2 = true;
      static bool prevEnv2GateState1 = false;
      static bool currentEnv2GateState1 = false;
      if (lfo1.getWave(micros()) > 2047) {
        currentEnv2GateState1 = true;
      } else {
        currentEnv2GateState1 = false;
      }
      if (currentEnv2GateState1 && !prevEnv2GateState1 && trigger2ENV2 == false) {
        // Start the envelope
        env2.noteOn(micros());
      } else if (!currentEnv2GateState1 && prevEnv2GateState1 && trigger2ENV2 == false) {
        // Stop the envelope
        env2.noteOff(micros());
      }
      prevEnv2GateState1 = currentEnv2GateState1;

      break;
    default:
  
      break;
  }

  lfo2.setWaveForm(lfo2_waveformIndex);
  lfo2.setAmpl(lfo2_amp);
  if (!lfo2Mode) {
    lfo2.setMode(lfo2Mode);
    lfo2.setMode0Freq(lfo2_freq, micros());
    if (digitalRead(LFO2_sync) == HIGH && trigger2LFO2 == false) {  //EXT Trigger
      lfo2.sync(micros());
    }
  } else {
    lfo2.setMode(lfo2Mode);
    lfo2.setMode1Bpm(bpm);
    lfo2.setMode1Rate(lfo2_rate);
  }

  switch (lfo2_pathsIndex) {  //"None", "Pitch", "SYNC", "Cutoff", "Amp", "ENV2 EXT Trigger"
    case 0:
      lfo22ENV2 = false;
      setVoltage(LFO_dac_cs, mcp4822_channel_b, 0);
      break;
    case 1:
      lfo22ENV2 = false;
      setVoltage(LFO_dac_cs, mcp4822_channel_b, lfo2.getWave(micros()));
      digitalWrite(A_1, HIGH);
      digitalWrite(B_1, HIGH);
      digitalWrite(C_1, LOW);
      break;
    case 2:
      lfo22ENV2 = false;
      setVoltage(LFO_dac_cs, mcp4822_channel_b, lfo2.getWave(micros()));
      digitalWrite(A_1, LOW);
      digitalWrite(B_1, LOW);
      digitalWrite(C_1, LOW);
      break;
    case 3:
      lfo22ENV2 = false;
      setVoltage(LFO_dac_cs, mcp4822_channel_b, lfo2.getWave(micros()));
      digitalWrite(A_1, HIGH);
      digitalWrite(B_1, LOW);
      digitalWrite(C_1, LOW);
      break;
    case 4:
      lfo22ENV2 = false;
      setVoltage(LFO_dac_cs, mcp4822_channel_b, lfo2.getWave(micros()));
      digitalWrite(A_1, LOW);
      digitalWrite(B_1, HIGH);
      digitalWrite(C_1, LOW);
      break;
    case 5:
      lfo22ENV2 = true;
      static bool prevEnv2GateState2 = false;
      static bool currentEnv2GateState2 = false;
      if (lfo2.getWave(micros()) > 2047) {
        currentEnv2GateState2 = true;
      } else {
        currentEnv2GateState2 = false;
      }
      if (currentEnv2GateState2 && !prevEnv2GateState2 && trigger2ENV2 == false) {
        // Start the envelope
        env2.noteOn(micros());
      } else if (!currentEnv2GateState2 && prevEnv2GateState2 && trigger2ENV2 == false) {
        // Stop the envelope
        env2.noteOff(micros());
      }
      prevEnv2GateState2 = currentEnv2GateState2;

      break;
    default:
      break;
  }

  switch (trigger_pathsIndex) {  //"None", "SYNC", "LFO1 SYNC", "LFO2 SYNC", "ENV2 Trigger"
    case 0:
      trigger2SYNC = false;
      trigger2LFO1 = false;
      trigger2LFO2 = false;
      trigger2ENV2 = false;
      break;
    case 1:
      trigger2SYNC = true;
      trigger2LFO1 = false;
      trigger2LFO2 = false;
      trigger2ENV2 = false;
      break;
    case 2:
      trigger2SYNC = false;
      trigger2LFO1 = true;
      trigger2LFO2 = false;
      trigger2ENV2 = false;
      break;
    case 3:
      trigger2SYNC = false;
      trigger2LFO1 = false;
      trigger2LFO2 = true;
      trigger2ENV2 = false;
      break;
    case 4:
      trigger2SYNC = false;
      trigger2LFO1 = false;
      trigger2LFO2 = false;
      trigger2ENV2 = true;
      break;
    default:
      break;
  }
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
